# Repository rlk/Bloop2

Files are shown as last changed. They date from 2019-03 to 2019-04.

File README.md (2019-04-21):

# Bloop2 — Dual Op-Amp Boosted Loop Switcher

Bloop2 is an effects loop switcher. It has Instrument Input and Amplifier Output jacks, plus effects loop Send and Return jacks with a single stomp button to switch that loop in or out.

Because it's often desirable to run the effects loop louder than the instrument signal, Bloop2 provides volume controls at both the Send and Return, with a maximum gain of around 10. When switched off, the circuit is fully bypassed.

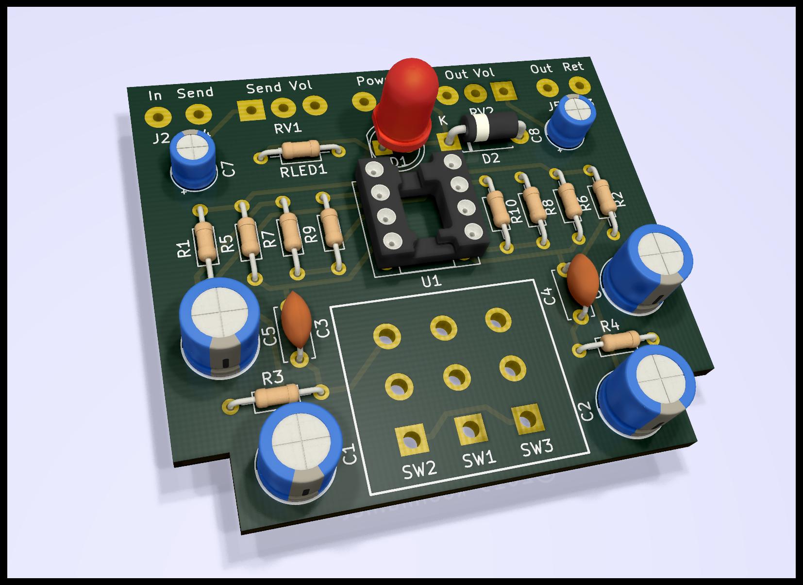
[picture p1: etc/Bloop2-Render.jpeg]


- [Schematic PNG](etc/Bloop2-Schematic.png)
- [Schematic PDF](etc/Bloop2-Schematic.pdf)
- [Hammond 1590B Drill Template SVG](etc/Bloop2-Drill-Template.svg)
- [PCB Prerendering](etc/Bloop2-Render.jpeg)
- [Gerber Files](etc/gerber)

Finished photos:

- [Enclosure](etc/Bloop2-Enclosure.jpeg)
- [Guts](etc/Bloop2-Guts.jpeg)

## Design notes

- The overall structure uses a constant gain with a volume control at the output.
	- As opposed to a variable gain.
	- This makes attenuation possible with a non-inverting amplifier.
	- This also makes it possible to dial back noise.

- The schematic specifies a TL072, but any standard pin-out dual op amp will do.
	- Op amp selection will not make a significant difference in color, as this circuit remains squarely within the common mode when correctly powered.

- The voltage requirement is entirely determined by the op amp. 
	- I use a TLE2072 which is within spec at either V+ = 9V or 18V. 

- The PCB is sized and shaped to fit a Hammond 1590B.
	- The 1590B is 56mm wide overall, but only 44mm wide at the ends. Thus the cutouts.
	- The PCB is limited to 50mm x 50mm to fit the cheap option at [DirtyPCBs].

- The PCB layout dictates the pin pitch of the stomp switch.
	- The current design specifies an E-Switch FS57003PLT2B2M2QE, which has 5.3mm x 4.8mm pitch.

- D2 can be any Schottky larger than V+.
	- They tend to cost the same regardless of voltage.

- The LED is specified at V+ = 9V, Vf = 2.2V, If = 20mA.
	- RLED1 = (9.0 - 2.2) / 0.020 = 340Ω.
	- Watch out for over-current on your LED with higher V+.
		- Or don't. It's probably fine at 40mA.

- R1 = R2.
	- They form a voltage divider giving the reference voltage.

- C1 and C2 values are cargo-culted to 47uF from common designs.
	- These values are pretty arbitrary.
		- Though the circuit will take a moment to start up if too small.
	- They match C5 and C6 by coincidence. I guess this eases sourcing.

- The two channels are identical.
	- Component value selections should be consistent between the two.
	- Though it's rational for the maximum Output gain to be lower than the maximum Send gain, if desired, since the loop is usually hotter than the line and Send usually amplifies while Output attenuates.

- R3 and C3 form a high-pass filter on the input.
	- The 3dB point is 1 / (2π R3 C3) = 1.6Hz.

- R3 = R5.
	- As a rule, R5 >> R1.
	- It's not strictly necessary that R3 = R5, except that both applications call for large R, and I appreciate the symmetry whereby two distinct potentials are established on either side of C3.

- Gain is 1 + R9 / R7.
	- With R9 = 22K and R7 = 2.2K, voltage gain is 11.
	- Keep R7 and R9 low to eliminate noise. Effectively zero current flows here.

- C5 is needed to eliminate DC gain, but incurs a high-pass filter on the feedback.
	- The value is selected to impedance match R7 at a frequency well below the audio band.
	- The 3db point is 1 / (2π R7 C5) = 1.5Hz.
	- The motivation to keep R7 and R9 small leads to large C5 ([AoE] 4.2.2.A).

- C7 and RV1 form a high-pass filter on the output.
	- The 3dB point is 1 / (2π RV1 C7) = 1.6Hz.
	- Larger RV1 permits a smaller C7 if desired.
	- C7 need not be polar, but capacitor type seems to a have a significant impact on color here.

- Pin 3 of RV1 and RV2 must be grounded, but it's not strictly necessary to ground at the given PCB pad.

- The circuit and signal grounds are completely separate, as designed. You'll probably want to tie them together. This is most easily done off-board, by wiring the negative terminal of the power jack to the sleeve terminal of one of the audio jacks.

## Analysis

To measure the circuit's effect on the input, here are a few screenshots from my scope. These show one channel of the device acting on a 1Hz 1Vpp square wave. Channel 1 displays the Instrument Input, at the bottom, and channel 2 displays the Send output, at the top. The volume is tuned to unity. The two traces appear identical.

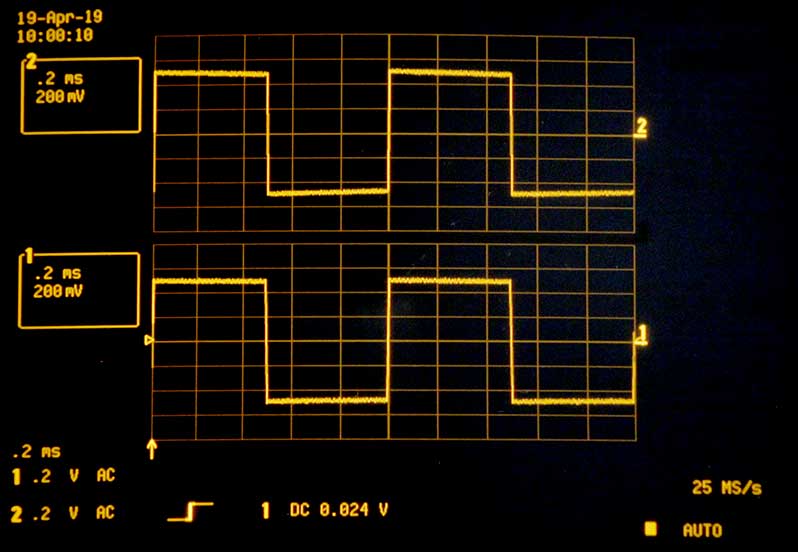
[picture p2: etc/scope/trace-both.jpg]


To see a difference, overlay the two traces, set an offset of -0.5V, and zoom in. The two traces clearly differ. The input is the flatter one. But they are within 10mV of one another, and environmental noise dominates at this scale.

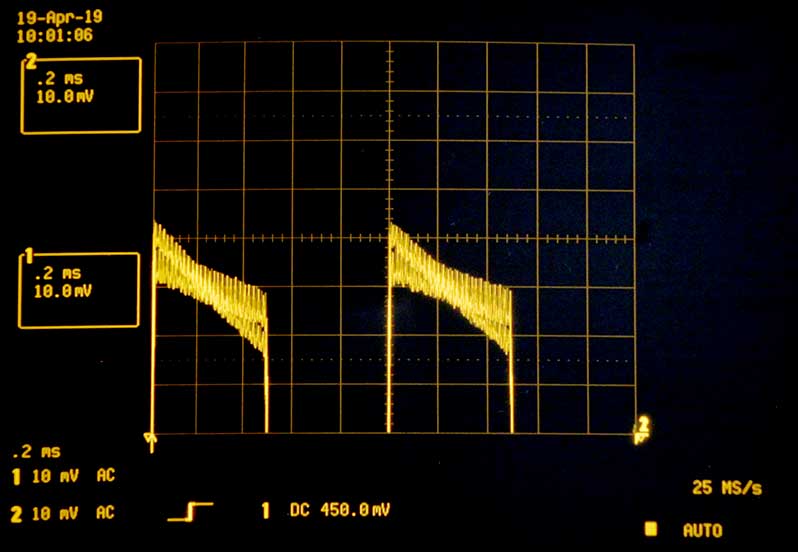
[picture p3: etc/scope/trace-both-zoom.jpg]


To analyze the true effect of the circuit, compute the difference between the input and output, similarly zoomed. We see noise on the scale of 10mV peak-to-peak, centered on zero. Spikes appear at the transitions indicating a minor phase shift in the output. The difference, for the most part, remains near zero.

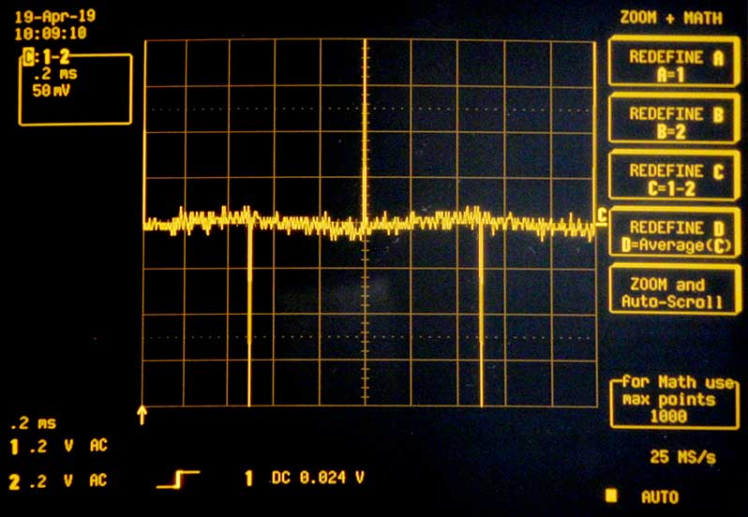
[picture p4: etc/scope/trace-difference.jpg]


To quantify the effect, compute the running average of the difference to eliminate noise. This demonstrates a deviation from square that is indeed around 10mV, or 1% of the amplitude of the input.

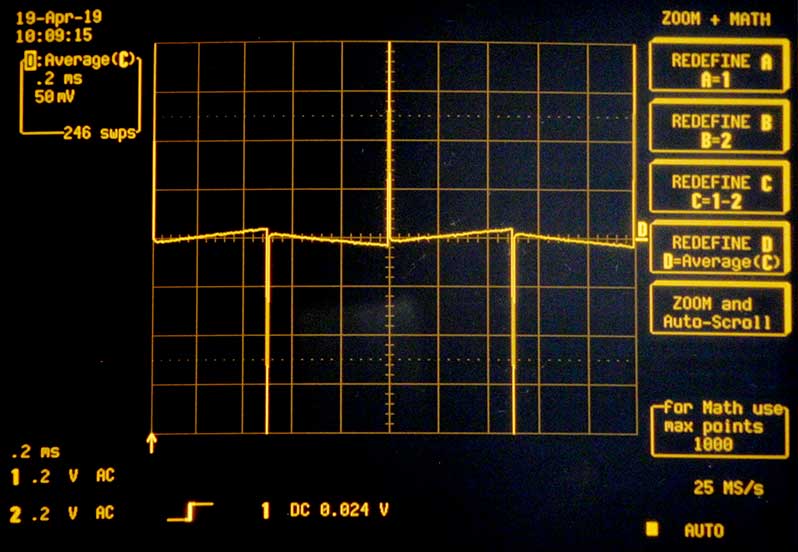
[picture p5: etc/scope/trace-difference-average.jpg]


The spike in the difference indicates a tiny phase shift in the output. Reducing the time interval lets us quantify it.

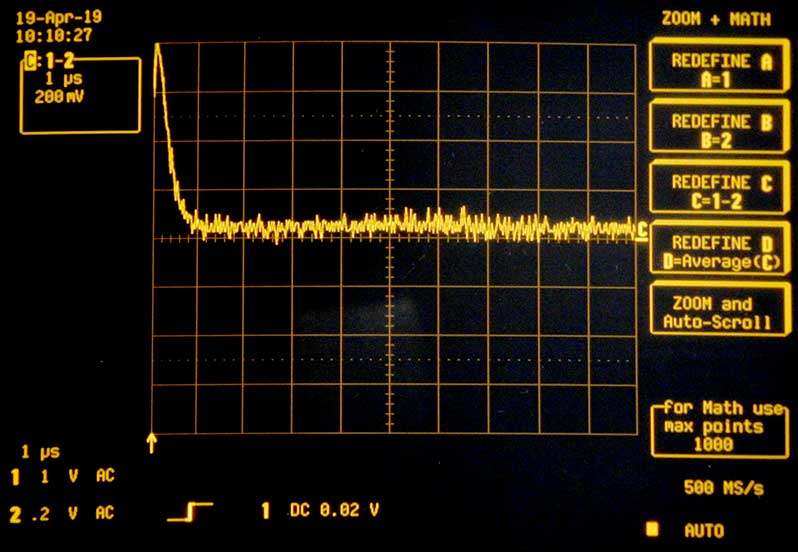
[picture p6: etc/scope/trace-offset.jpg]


Smoothing shows this delay to be at most 1 microsecond, far below the audible band.

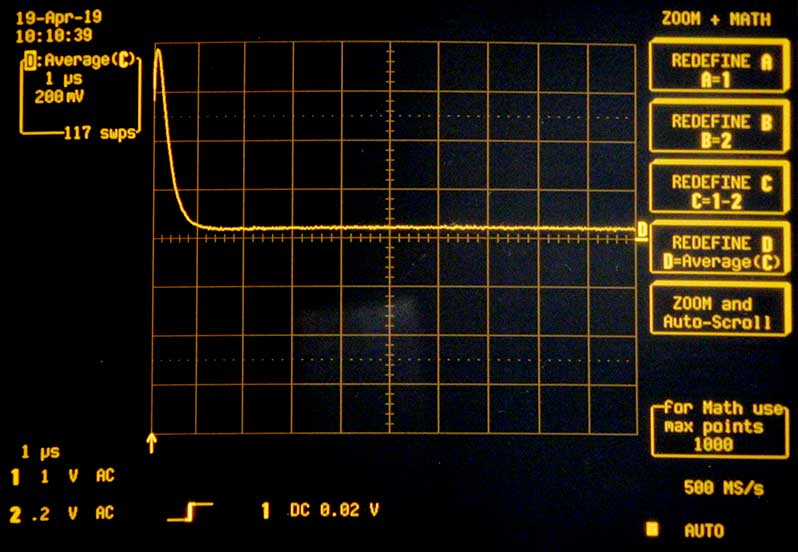
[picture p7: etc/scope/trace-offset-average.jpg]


Performance of the other channel is effectively identical.

[AoE]: https://artofelectronics.net
[DirtyPCBs]: https://dirtypcbs.com

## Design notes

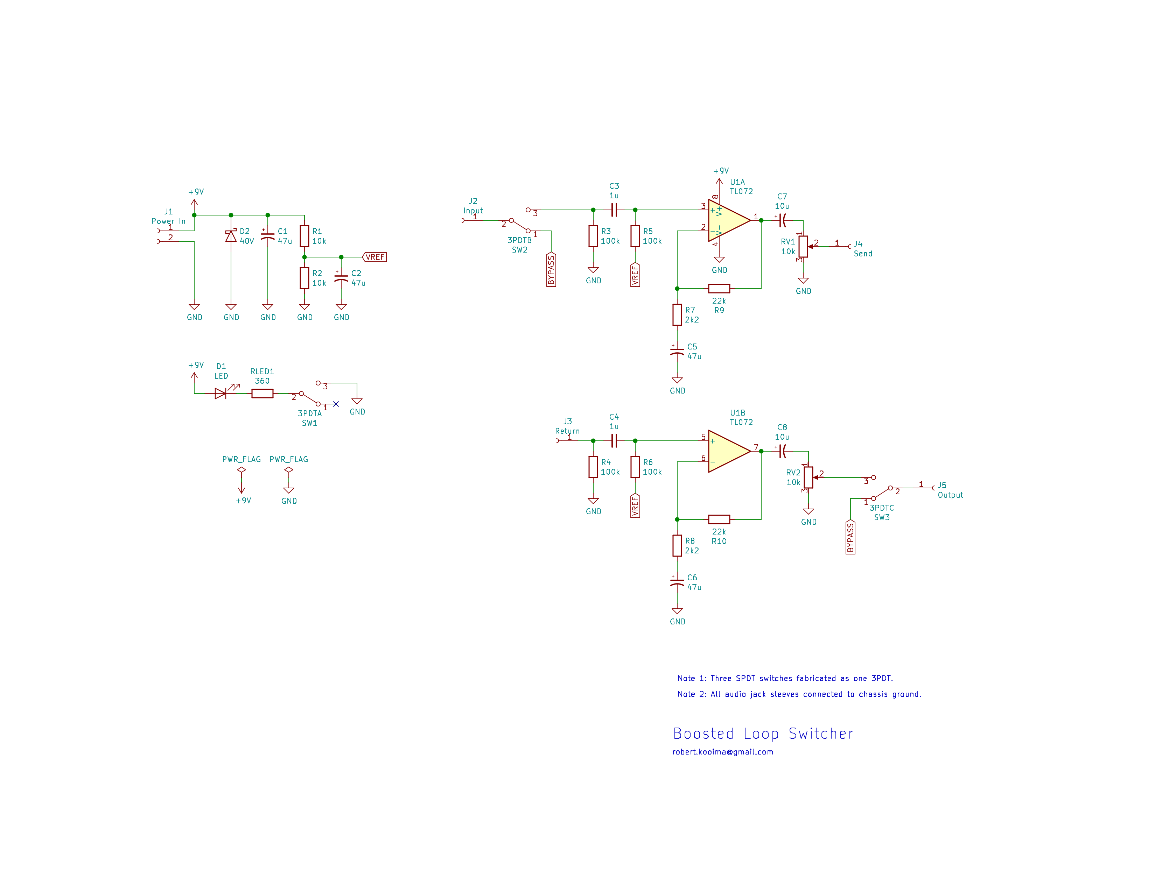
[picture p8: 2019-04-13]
etc/Bloop2-Schematic.png

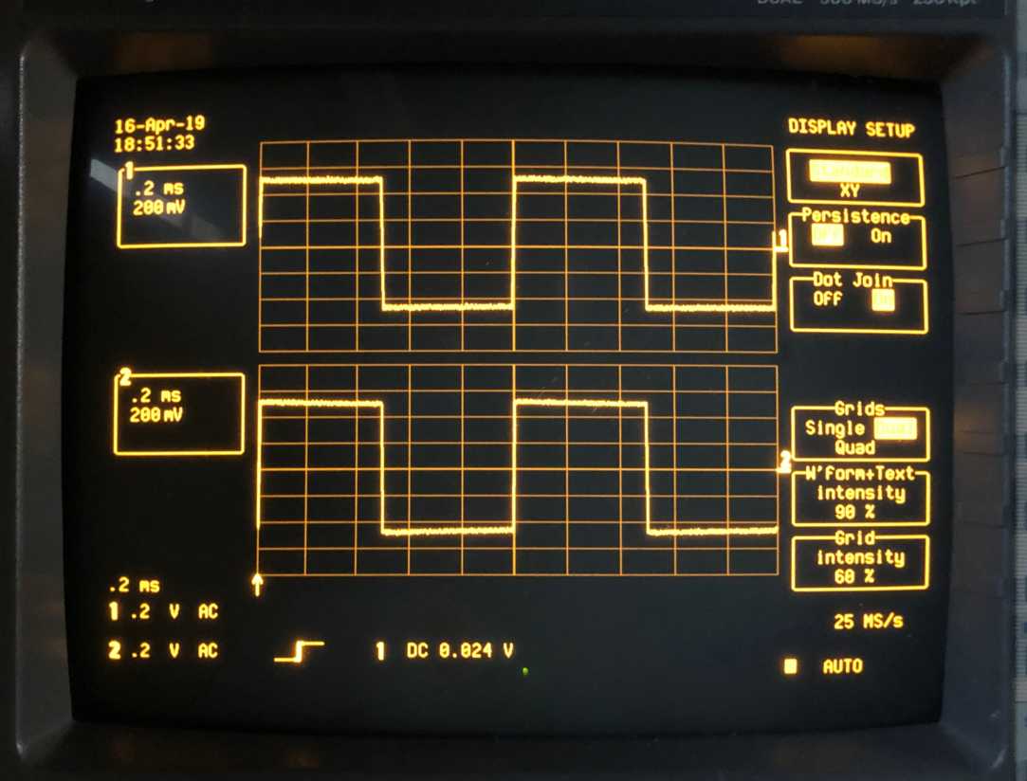
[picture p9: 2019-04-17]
etc/scope/scope-traces.jpg

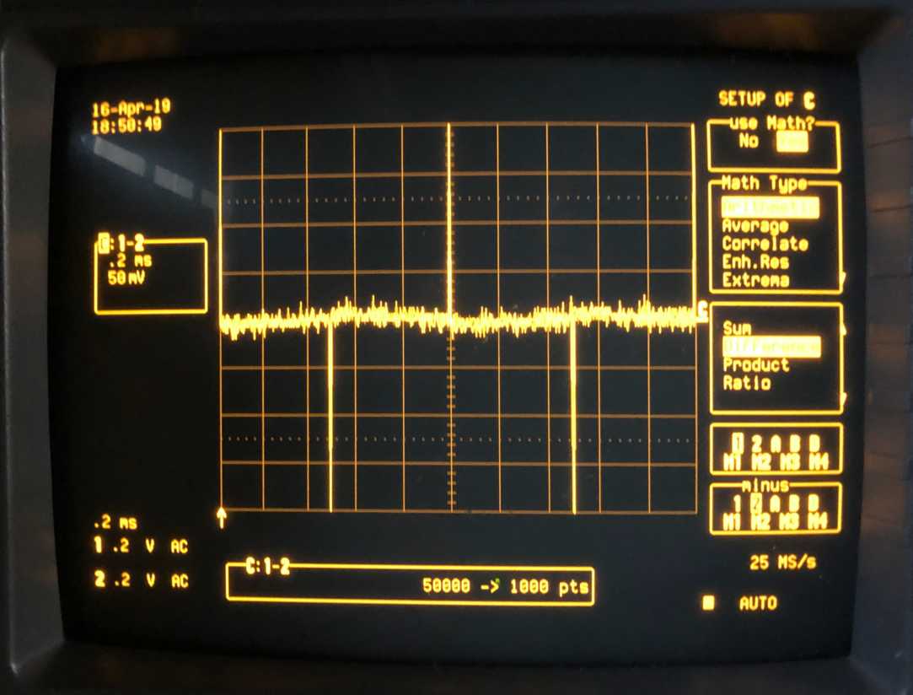
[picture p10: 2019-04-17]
etc/scope/scope-difference.jpg

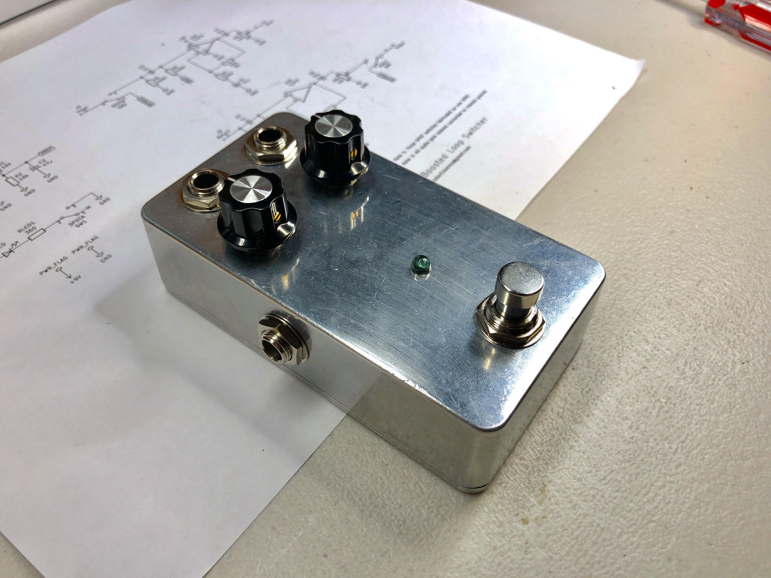
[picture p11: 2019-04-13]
etc/Bloop2-Enclosure.jpeg

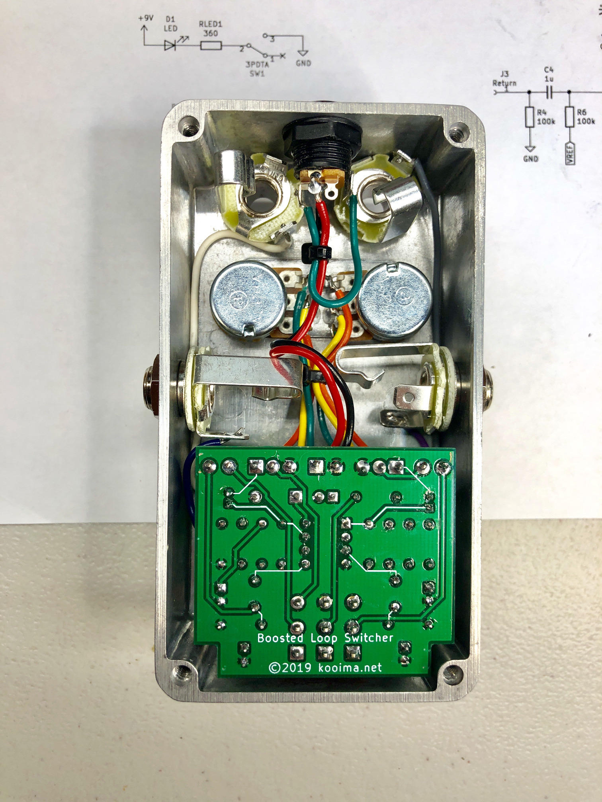
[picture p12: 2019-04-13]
etc/Bloop2-Guts.jpeg

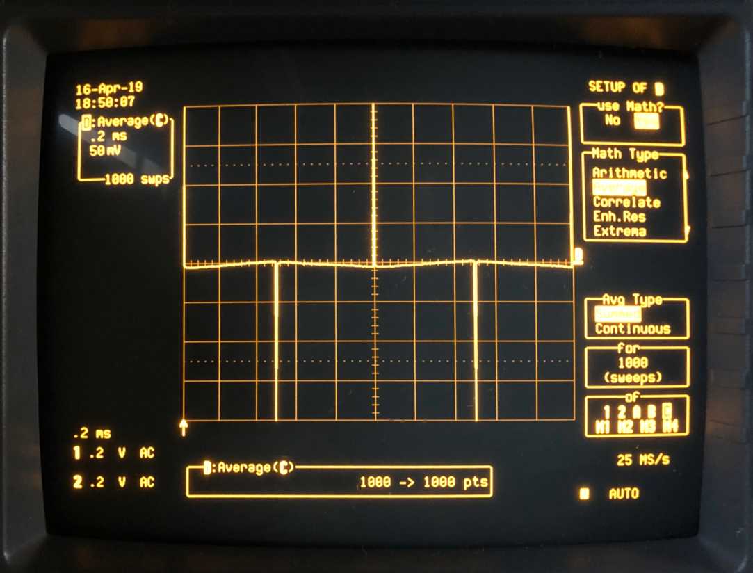
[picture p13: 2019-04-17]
etc/scope/scope-average.jpg

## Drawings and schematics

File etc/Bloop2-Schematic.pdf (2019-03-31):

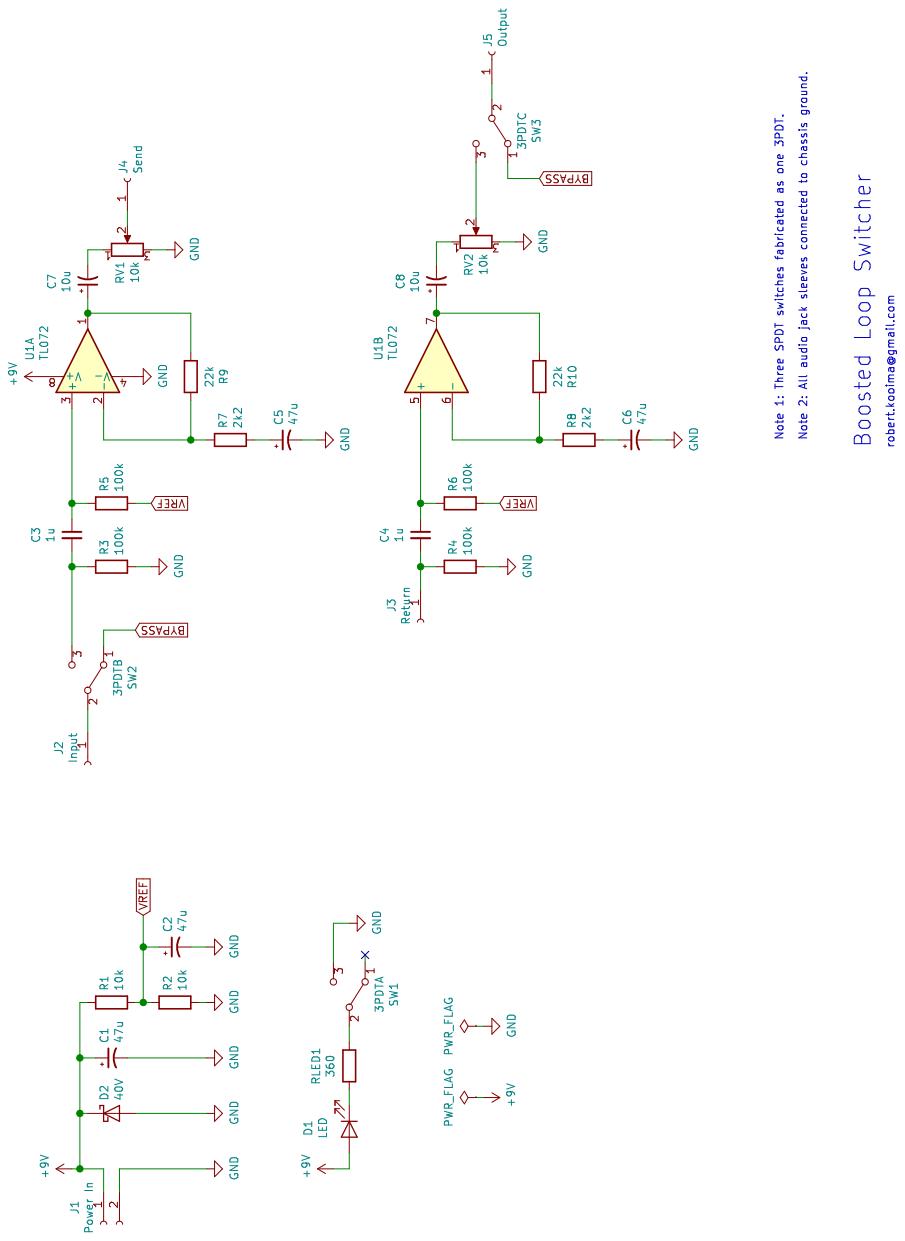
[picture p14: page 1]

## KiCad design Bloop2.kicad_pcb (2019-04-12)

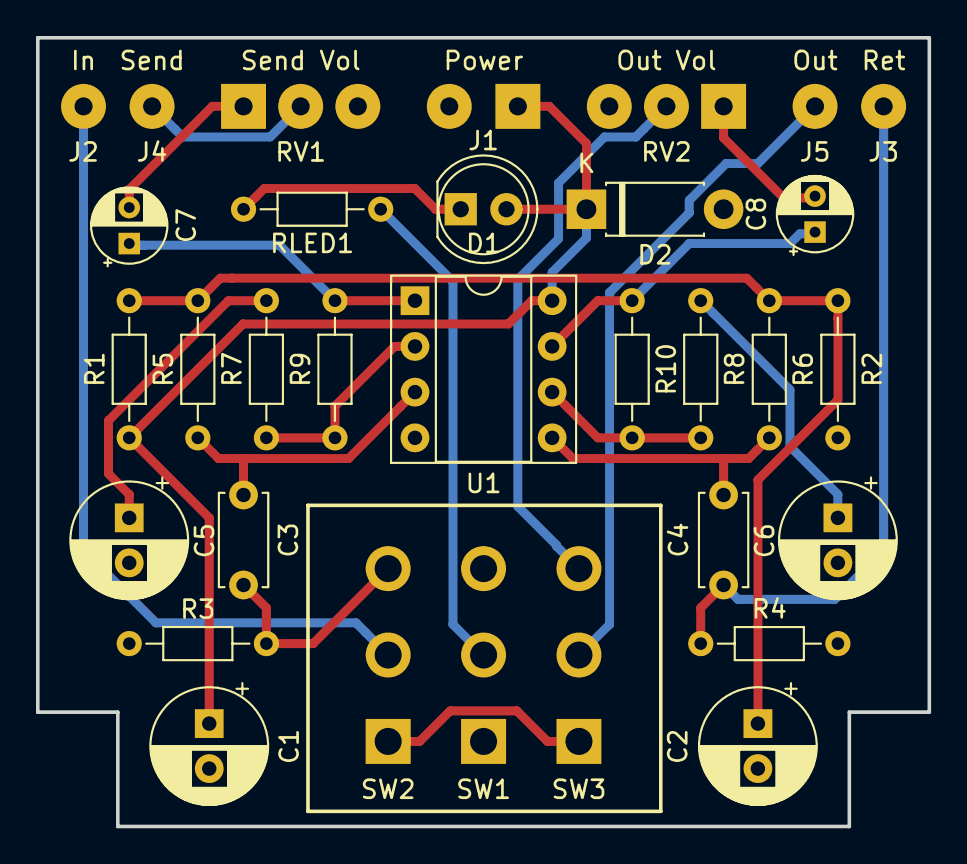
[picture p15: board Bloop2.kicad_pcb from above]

Board: 2 copper layers, 49.5 x 43.8 mm, 32 parts (0 on the bottom side), 22 nets.

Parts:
C1, C2, C5, C6: 47u; CP_Radial_D6.3mm_P2.50mm
C3, C4: 1u; C_Disc_D5.0mm_W2.5mm_P5.00mm
C7, C8: 10u; CP_Radial_D4.0mm_P2.00mm
D1: LED; LED_D5.0mm
D2: 40V; D_DO-41_SOD81_P7.62mm_Horizontal
J1: Power In; SolderWirePad_1x02_P3.81mm_Drill1mm
J2: Input; SolderWirePad_1x01_Drill1mm
J3: Return; SolderWirePad_1x01_Drill1mm
J4: Send; SolderWirePad_1x01_Drill1mm
J5: Output; SolderWirePad_1x01_Drill1mm
R1, R2: 10k; R_Axial_DIN0204_L3.6mm_D1.6mm_P7.62mm_Horizontal
R3, R4, R5, R6: 100k; R_Axial_DIN0204_L3.6mm_D1.6mm_P7.62mm_Horizontal
R7, R8: 2k2; R_Axial_DIN0204_L3.6mm_D1.6mm_P7.62mm_Horizontal
R9, R10: 22k; R_Axial_DIN0204_L3.6mm_D1.6mm_P7.62mm_Horizontal
RLED1: 360; R_Axial_DIN0204_L3.6mm_D1.6mm_P7.62mm_Horizontal
RV1, RV2: 10k; SolderWirePad_1x03_P3.175mm_Drill1mm
SW1: 3PDTA; SolderWirePad_1x03_P9.60mm_Drill1.5mm
SW2: 3PDTB; SolderWirePad_1x03_P9.60mm_Drill1.5mm
SW3: 3PDTC; SolderWirePad_1x03_P9.60mm_Drill1.5mm
U1: TL072; DIP-8_W7.62mm_Socket

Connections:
+9V: C1.1, D1.2, D2.1, J1.1, R1.1, U1.8
BYPASS: SW2.1, SW3.1
GND: C1.2, C2.2, C5.2, C6.2, D2.2, J1.2, R2.2, R3.2, R4.2, RV1.3, RV2.3, SW1.3, U1.4
unnamed: C3.1, R5.1, U1.3
unnamed: C3.2, R3.1, SW2.3
unnamed: C4.1, R6.1, U1.5
unnamed: C4.2, J3.1, R4.1
unnamed: C5.1, R7.2
unnamed: C6.1, R8.2
unnamed: C7.1, R9.2, U1.1
unnamed: C7.2, RV1.1
unnamed: C8.1, R10.2, U1.7
unnamed: C8.2, RV2.1
unnamed: D1.1, RLED1.1
unnamed: J2.1, SW2.2
unnamed: J4.1, RV1.2
unnamed: J5.1, SW3.2
unnamed: R7.1, R9.1, U1.2
unnamed: R8.1, R10.1, U1.6
unnamed: RLED1.2, SW1.2
unnamed: RV2.2, SW3.3
VREF: C2.1, R1.2, R2.1, R5.2, R6.2

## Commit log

2019-02-28 Initial design of boosted loop switcher.
    A simple op-amp booster. Just putting some thoughts into a schematic.
    [Bloop2.kicad_pcb, Bloop2.sch]
2019-02-28 Feature complete device with first layout.
    [Bloop2.kicad_pcb, Bloop2.sch]
2019-02-28 Improved, compacted layout.
    [Bloop2.kicad_pcb, Bloop2.sch]
2019-02-28 Tuned layout.
    The moment you send a PCB off for printing, you think of a ton of obvious ideas for improvement.
    [Bloop2.kicad_pcb, Bloop2.sch]
2019-02-28 Fix design flaws detected in previous circuit.
    A previous design was printed and fabricated, revealing a number of problems.
    1. The pots were not appropriate for panel mounting. They were too short, leaving no room for the electrolitic capacitors.
    2. The switches were backwards on the schematic (easily resolvable in the wiring).
    3. The circuit cut the highs too much. This revision matches the input RC to the Timmy.
    This design mounts the footswitch on the PCB, which should give a secure enclosure mounting.
    [Bloop2.kicad_pcb, Bloop2.sch]
2019-03-04 Add Hammond 1590B drill template
2019-03-08 Add footprint for custom solder wire pad.
2019-03-08 Tweak LED resistor for selected LED.
    [Bloop2.sch]
2019-03-28 Add bias resistors. Overall shift toward more conservative design.
    [Bloop2.sch]
2019-03-28 Minor schematic layout tweaks.
    [Bloop2.sch]
2019-03-29 Tune component values.
    [Bloop2.sch]
2019-03-29 Add PDF of schematic
2019-03-29 Revert renaming TL072 to TLE2072.
    TLE2072 isn't in the library, so the net got scrambled.
    [Bloop2.sch]
2019-03-30 PCB layout draft
    [Bloop2.kicad_pcb, Bloop2.sch]
2019-03-30 Fix a few PCB labels
    [Bloop2.kicad_pcb]
2019-03-31 Specify polar output caps.
    Output cap type seems to have a significant effect on EQ. I'd like to leave this as an option for the builder, but leaving the schematic symbols non-polarized results in a backwards footprint on the 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
    [Bloop2.kicad_pcb, Bloop2.sch]
2019-03-31 Organize derived files in etc.
    [Bloop2-B.Cu.gbl, Bloop2-B.SilkS.gbo, Bloop2-Edge.Cuts.gm1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]
2019-03-31 Update schematic PDF
2019-04-12 Finalize notes and go to print
    [Bloop2-B.Cu.gbl, Bloop2-B.Mask.gbs, Bloop2-B.SilkS.gbo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]
2019-04-13 Add images and organize
    [Bloop2-B.Cu.gbl, Bloop2-B.Mask.gbs, Bloop2-B.SilkS.gbo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]
2019-04-13 Link Gerber files from README

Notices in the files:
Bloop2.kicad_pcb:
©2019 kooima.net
